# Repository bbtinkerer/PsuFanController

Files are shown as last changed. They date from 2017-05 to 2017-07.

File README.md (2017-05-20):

# Nintendo Classic Advantage Controller

By bbtinkerer (<http://bb-tinkerer.blogspot.com/>)

## Description
Simple ATtiny85 fan controller to turn a fan on/off based on temperature. Includes an LED as a temperature indicator. LED is dim at start of fan on temperature and blinks when above a max temperature. Fan is not PWM controlled since I am using a small 5V fan which is quiet running at 100%. The controller is in sleep state while the temperature is below the minimum threshold and wakes up every ~8 seconds to recheck the temperature. When temperature is above minimum threshold, the controller will stay awake checking every second till the temperature falls below the minimum threshold. Uses ds18b20 library by Davide Gironi.

## Configuration

Burn ATtiny85 with fuses with internal 8MHz oscillator, divide clock by 8, and disable brown out detection.

Component connections:

| Component | Pin# | Port |
|---|---|---|
| Fan | 3 | PB4  |
| LED | 5 | PB0  |
| DS18B20 | 2 | PB3  |

## Usage

Use Atmel Studio 7 to build and flash to your microcontroller. Alternatively, build and flash with your favorite AVR tool chain and programmers.

### Known Issues

If you discover any bugs, feel free to create an issue on GitHub fork and
send a pull request.

## Authors

* bbtinkerer (https://github.com/bbtinkerer/)

## Contributing

1. Fork it
2. Create your feature branch (`git checkout -b my-new-feature`)
3. Commit your changes (`git commit -am 'Add some feature'`)
4. Push to the branch (`git push origin my-new-feature`)
5. Create new Pull Request

## License

This program is free software: you can redistribute it and/or modify it under the terms of the GNU General Public License as published by the Free Software Foundation, either version 3 of the License, or (at your option) any later version.

This program is distributed in the hope that it will be useful, but WITHOUT ANY WARRANTY; without even the implied warranty of MERCHANTABILITY or FITNESS FOR A PARTICULAR PURPOSE.  See the GNU General Public License for more details.

You should have received a copy of the GNU General Public License along with this program.  If not, see <http://www.gnu.org/licenses/>.

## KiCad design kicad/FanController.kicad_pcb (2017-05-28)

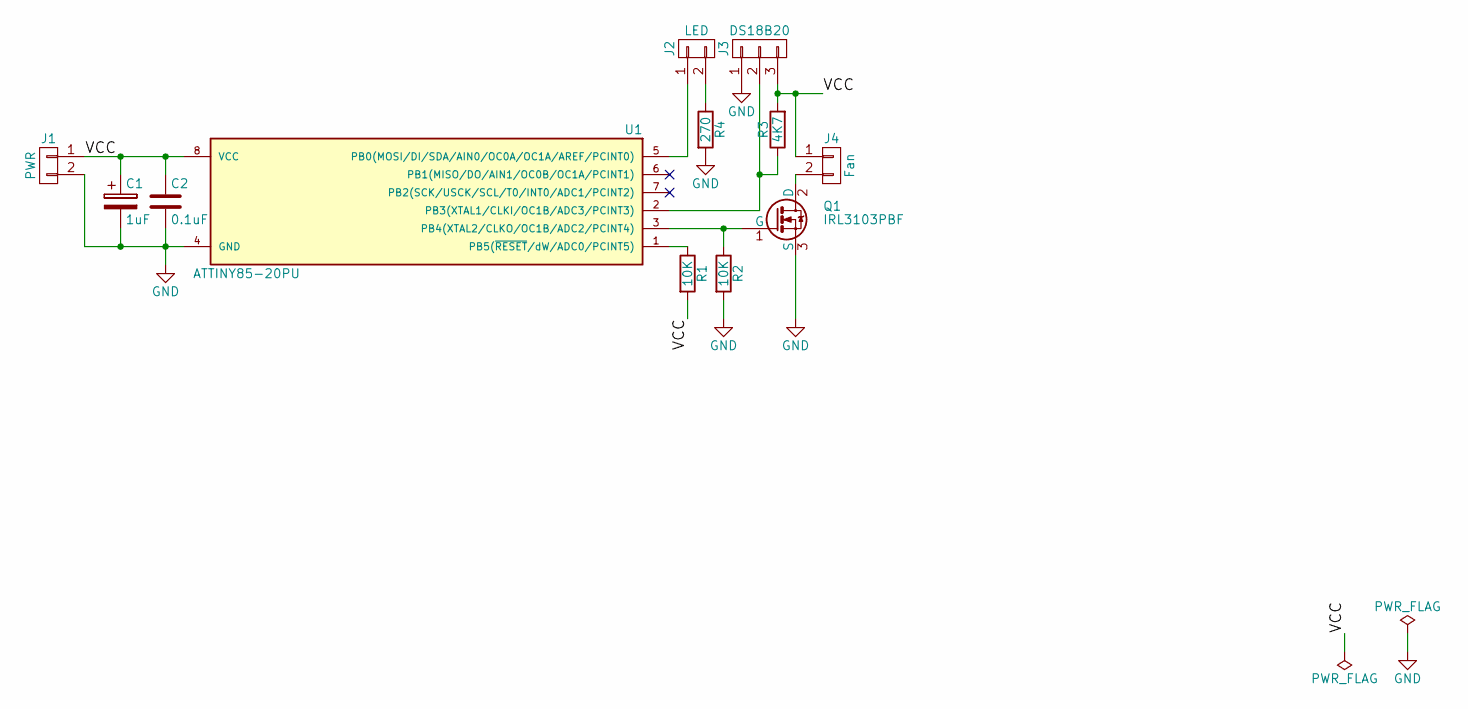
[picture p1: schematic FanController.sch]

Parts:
C1: 1uF; CP_Radial_Tantal_D5.0mm_P5.00mm
C2: 0.1uF; C_Rect_L9.0mm_W4.9mm_P7.50mm_MKT
J1: PWR; Pin_Header_Straight_1x02_Pitch2.54mm
J2: LED; Pin_Header_Straight_1x02_Pitch2.54mm
J3: DS18B20; Pin_Header_Straight_1x03_Pitch2.54mm
J4: Fan; Pin_Header_Straight_1x02_Pitch2.54mm
Q1: IRL3103PBF; TO-220_Vertical
R1, R2: 10K; R_Axial_DIN0207_L6.3mm_D2.5mm_P10.16mm_Horizontal
R3: 4K7; R_Axial_DIN0207_L6.3mm_D2.5mm_P10.16mm_Horizontal
R4: 270; R_Axial_DIN0207_L6.3mm_D2.5mm_P10.16mm_Horizontal
U1: ATTINY85-20PU; DIP-8_W7.62mm

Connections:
/VCC: C1.1, C2.1, J1.1, J3.3, J4.1, R1.2, R3.2, U1.8 (VCC)
GND: C1.2, C2.2, J1.2, J3.1, Q1.3 (S), R2.2, R4.2, U1.4 (GND)
unnamed: J2.1, U1.5 (PB0(MOSI/DI/SDA/AIN0/OC0A/OC1A/AREF/PCI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)
unnamed: J2.2, R4.1
unnamed: J3.2, R3.1, U1.2 (PB3(XTAL1/CLKI/OC1B/ADC3/PCINT3))
unnamed: J4.2, Q1.2 (D)
unnamed: Q1.1 (G), R2.1, U1.3 (PB4(XTAL2/CLKO/OC1B/ADC2/PCINT4))
unnamed: R1.1, U1.1 (PB5(~RESET~/dW/ADC0/PCINT5))

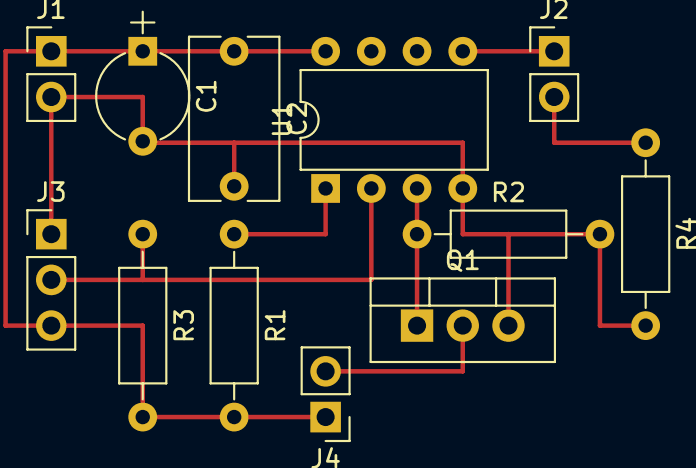
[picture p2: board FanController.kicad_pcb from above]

Board: 2 copper layers, 12 parts (0 on the bottom side), 8 nets.

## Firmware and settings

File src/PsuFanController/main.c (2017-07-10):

/*
* Power Supply Unit Fan Controller 
* Copyright (c) 2017 bbtinkerer
*
* Simple ATtiny85 fan controller to turn a fan on/off based on temperature. 
* Includes an LED as a temperature indicator. LED is dim at start of fan on
* temperature and blinks when above a max temperature. Fan is not PWM 
* controlled since I am using a small 5V fan which is quiet running at 100%. 
* The controller is in sleep state while the temperature is below the minimum 
* threshold and wakes up every ~8 seconds to recheck the temperature.
* When temperature is above minimum threshold, the controller will stay
* awake checking every second till the temperature falls below the minimum
* threshold. Uses ds18b20 library by Davide Gironi.
*
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
* You should have received a copy of the GNU General Public License
* along with this program.  If not, see <http://www.gnu.org/licenses/>.
 */

#include <avr/sleep.h>
#include <avr/interrupt.h>
#include <avr/power.h>
#include <avr/wdt.h>
#include <util/delay.h>
#include "ds18b20.h"

#define PWM_FULL 255
#define FAN_ON_TEMPERATURE 35
#define FAN_OFF_TEMPERATURE 30
#define MAX_TEMPERATURE 45

int fanOn = 0;

void enableSleep();

int main(void)
{
   double currentTemperature = 0;
   int dutyCycle = 0;
   // Set ports to output
   // PB0 - PWM LED indicator
   // PB4 - Fan
   // not shown PB3, set in ds18b20.h for temperature sensor
   DDRB = (1 << PB4) | (1 << PB0);
   PORTB = (1 << PB0);
   
   // interweb said unused ports should not be floating
   // PB1 and PB2 unused, set to input (default)
   // and enable the internal pull-up resistor
   PORTB |= (1 << PB1) | (1 << PB2);
   
   // turn off ADC since not using it
   ADCSRA &= ~(1 << ADEN);
   // datasheet said analog comparator can be turned off, set ACD to 1
   // said to turn off interrupt before turning ACD off
   ACSR &= ~(1 << ACIE);
   ACSR |= (1 << ACD);
   
   // disable interrupts
   cli();
   
   // MCU Status Register - clear watchdog timer reset flag
   MCUSR &= ~(1 << WDRF);
   // Watchdog Timer Control Register - watchdog change enable, watchdog enable
   WDTCR |= ((1 << WDCE) | (1 << WDE));
   // Watchdog Timer Control Register - enable interrupt, set to 8s
   WDTCR = ((1 << WDIE) | (1 << WDP3) | (1 << WDP0));// | (1 << WDP1) | (1 << WDP0));
   
   while (1)
   {
      currentTemperature = ds18b20_gettemp();

      if(currentTemperature >= FAN_OFF_TEMPERATURE)
      {
         if(currentTemperature >= FAN_ON_TEMPERATURE && !fanOn)
         {
            // turn fan on full, only 5v and pretty quiet so no need to PWM
            PORTB |= (1 << PB4);
            fanOn = 1;
         }
         
         if(fanOn)
         {
            if(currentTemperature >= MAX_TEMPERATURE)
            {
               // Fast PWM reset, set ports to normal operation
               TCCR0A &= ~((1 << COM0A1) | (1 << COM0A0));
               // turn off PWM
               TCCR0B &= ~(1 << CS00);
               // flash LED indicator
               PORTB ^= (1 << PB0);
            }
            else
            {
               // turn on LED as temperature indicator by brightness
               // scale dutyCycle from range from ON to MAX temp
               dutyCycle = (currentTemperature-FAN_OFF_TEMPERATURE) / (MAX_TEMPERATURE-FAN_OFF_TEMPERATURE) * PWM_FULL;
               if(dutyCycle > MAX_TEMPERATURE)
               {
                  dutyCycle = MAX_TEMPERATURE;
               }
               OCR0A = dutyCycle;
               
               // turn the PWM back on
               TCCR0A |= (1 << COM0A1) | (1 << WGM01) | (1 << WGM00);
               TCCR0B |= (1 << CS00);
            }
            
            // take a reading again after a second
            _delay_ms(1000);
         }
      }
      else
      {
         fanOn = 0;
      }
      
      if(!fanOn)
      {
         // Fast PWM reset, set ports to normal operation
         TCCR0A &= ~((1 << COM0A1) | (1 << COM0A0));
         // set ports low/off
         TCCR0B &= ~(1 << CS00);
         PORTB &= ~((1 << PB0) | (1 << PB4));
         enableSleep();
      }
   }
}

ISR(WDT_vect)
{
   // disable sleep on wakeup
   sleep_disable();
   
   // disable interrupts
   cli();
}

void enableSleep()
{
   set_sleep_mode(SLEEP_MODE_PWR_DOWN);
   sleep_bod_disable();
   sleep_enable();
   //enable interrupts
   sei();
   sleep_cpu();
}

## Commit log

2017-05-28 Add kicad project
    [FanController.kicad_pcb, FanController.sch]
2017-07-10 turn fan on/off at different temperatures
